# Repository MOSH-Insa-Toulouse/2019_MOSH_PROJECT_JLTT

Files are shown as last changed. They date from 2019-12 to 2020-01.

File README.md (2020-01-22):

# 2019_MOSH_PROJECT_JLTT : Kicad and Arduino LoraProject for SMART GAS sensor
> Loan Revardel / Jérémy Turi / Théo Zanchi / Thomas Lautrédou

#### <em> Key-words: </em> ```Arduino```, ```KiCad```, ```The Thing Network```, ```LoRa```, ```Node-RED```, ```IoT```, ```Gas sensor```.

This project was carried out as part of ISS (Innovative Smart Systems) 5th year at INSA Toulouse. The objective was to develop a gas sensor able to detect dangerous gases for human beings and communicating datas via Lora. Then, using the Node-RED software, we retrieved the data and displayed it on a graphical interface that the user could understand. As soon as a dangerous gas is detected, a buzzer is triggered to warn the user and avoid potential casualties. 

# Content of the Project

This repository contains : 
<ul>
<li><strong>KiCad files</strong> : We developed a shield for the gas sensor compatible with Arduino Uno (using <a href="http://kicad-pcb.org/">KiCad</a>) </li>
<li><strong>Arduino SW files</strong> : The source code we implemented on the microcontroller <a href="https://fr.rs-online.com/web/p/products/7589339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"> ATMEGA328 </a> (using <a href="https://www.arduino.cc/">Arduino IDE</a>)</li>
<li>A <strong>Node-RED dashboard</strong> to display datas retrieved from the gas sensor (using <a href="https://nodered.org/">Node-RED</a>)</li>
</ul>

# Overall components presentation
The goal of the project was to develop a prototype able to detect high dangerous gas concentration in a specific area. In this situation, a siren is triggered to alert people and avoid casualties. 

To do so, we used :
<ul>
<li>A <a href="https://store.arduino.cc/arduino-uno-rev3">Arduino Uno Board</a></li>
<li>A LoRa chip <a href="https://www.microchip.com/wwwproducts/en/RN2483">RN2483A</a></li>
<li>A <a href="http://wiki.seeedstudio.com/Grove-Gas_Sensor-MQ9/">Grove Gas Sensor (MQ9)</a></li>
<li>A potentiometer</li>
<li>A transistor <a href="http://www.vishay.com/docs/91291/91291.pdf">IRFZ44</a></li>
</ul>

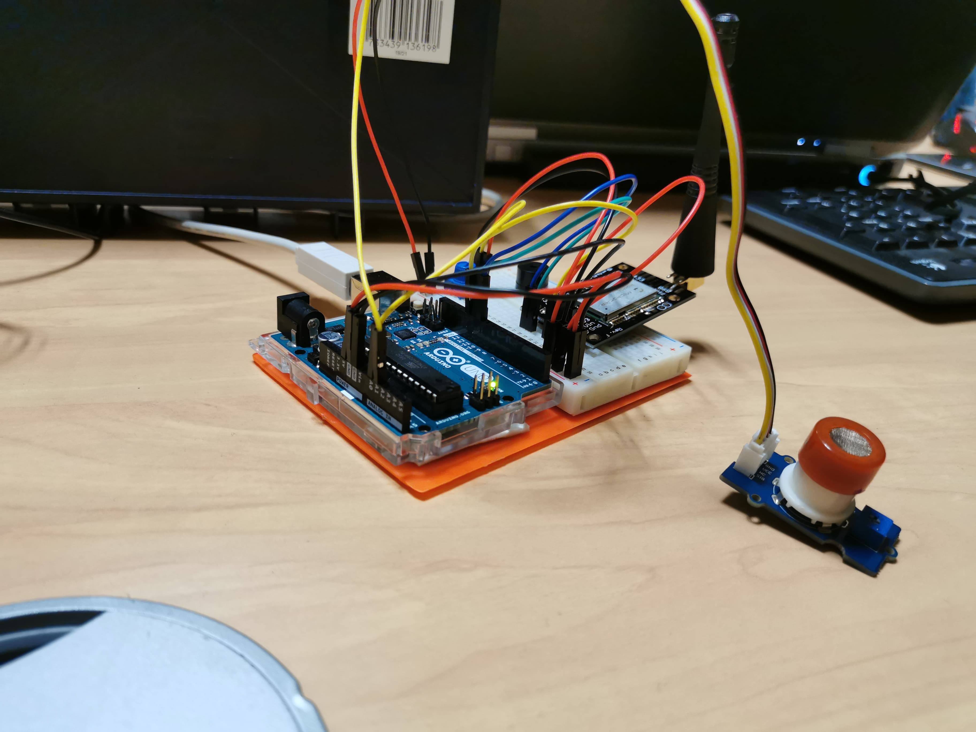
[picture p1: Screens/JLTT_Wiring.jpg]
JLTT_Wiring


### Dashboard

Then after creating a TTN application and registering our device, we used a ttn uplink node to receive the data sent to our TTN application. Finally, with some basic functions and chart blocs, we were able to display in a dashboard all the data in real time. You can find on the following figures the Node-Red flow and dashboard:

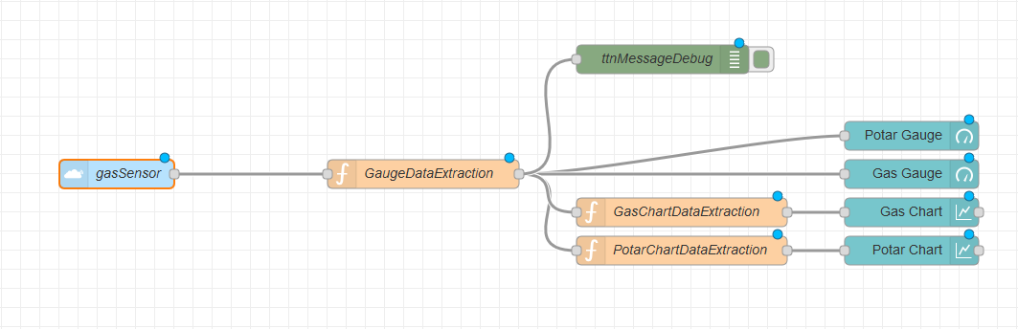
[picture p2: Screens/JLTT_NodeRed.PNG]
JLTT_NodeRed


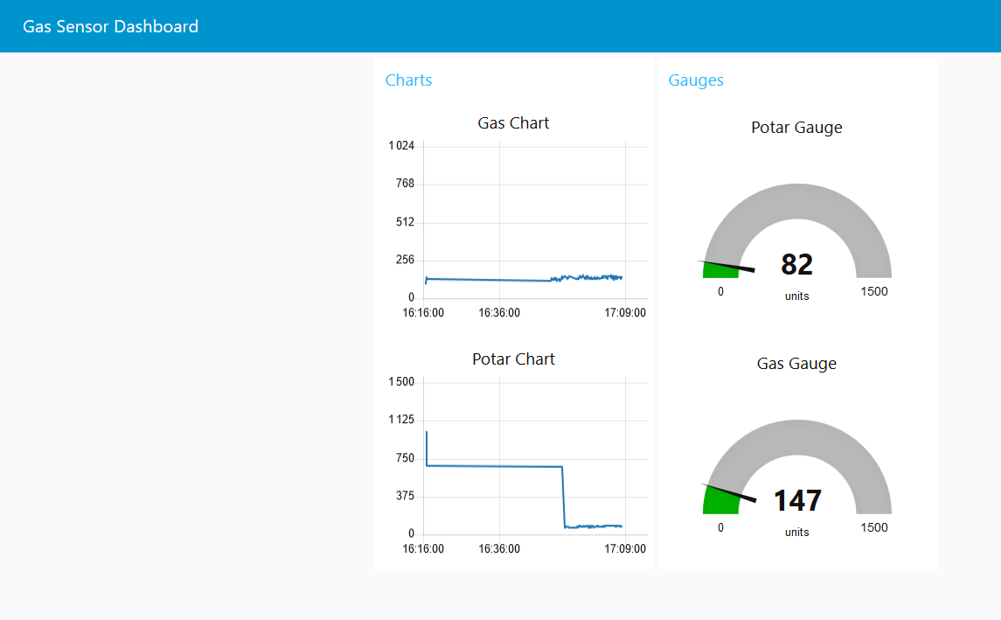
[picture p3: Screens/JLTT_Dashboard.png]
JLTT_Dashboard


### Energy consumption

During our smart device realization, we studied the energy consumption in order to optimize it. We found that we were consuming 355mA and 370mA during an emission. That is why we chose to define a sleep cycle. Indeed, every 8 seconds, our smart device wake up, read the sensor value and send it to TTN. To realize this, we used an Arduino library by convenience and lack of time:

JLTT_lowpower

This sleep cycle allows a great reduction of energy consumption and an increasing of battery lifetime.

## KiCad

In this repository, you can find KiCad files of our project. We designed an Arduino shield based on the sensor we produced at the AIME laboratory. This shield is composed of the sensor, a buzzer, a NRF2483 LoRa ship and an adapter circuit for the gas sensor. You can see on the following figure the schematics we designed with KiCad:

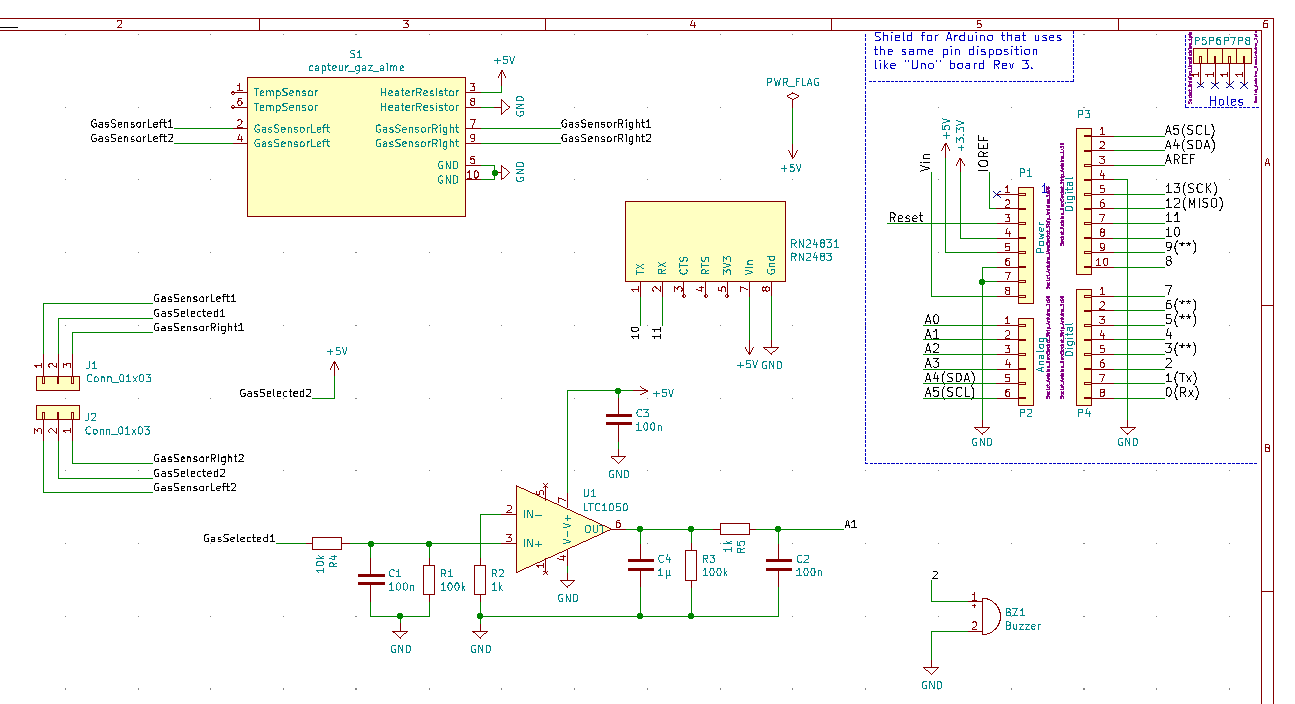
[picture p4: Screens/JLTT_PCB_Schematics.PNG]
JLTT_PCB_Schematics


After the schematics design, we exported the net file and realized the PCB routing that you can find with the following figures:

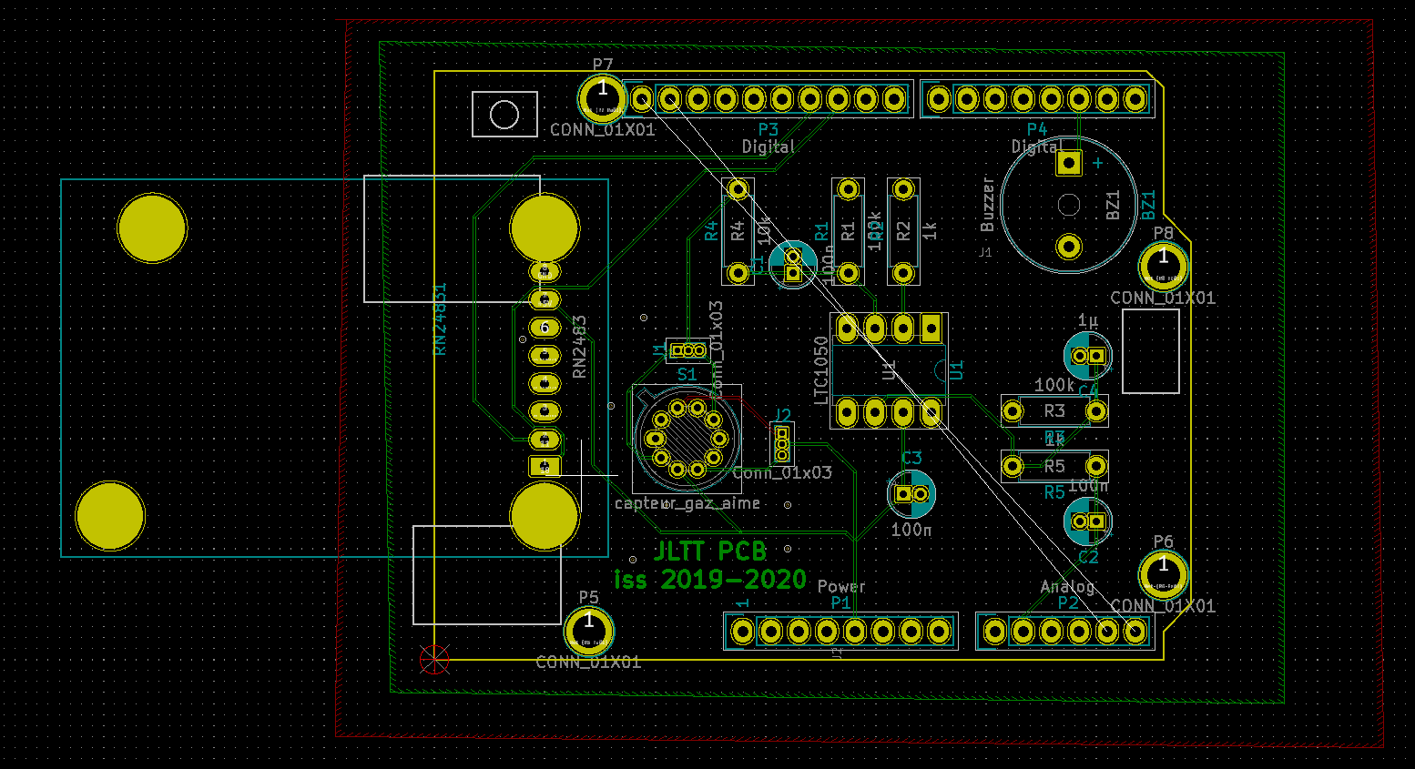
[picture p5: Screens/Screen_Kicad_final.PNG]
JLTT_PCB_Routing_1


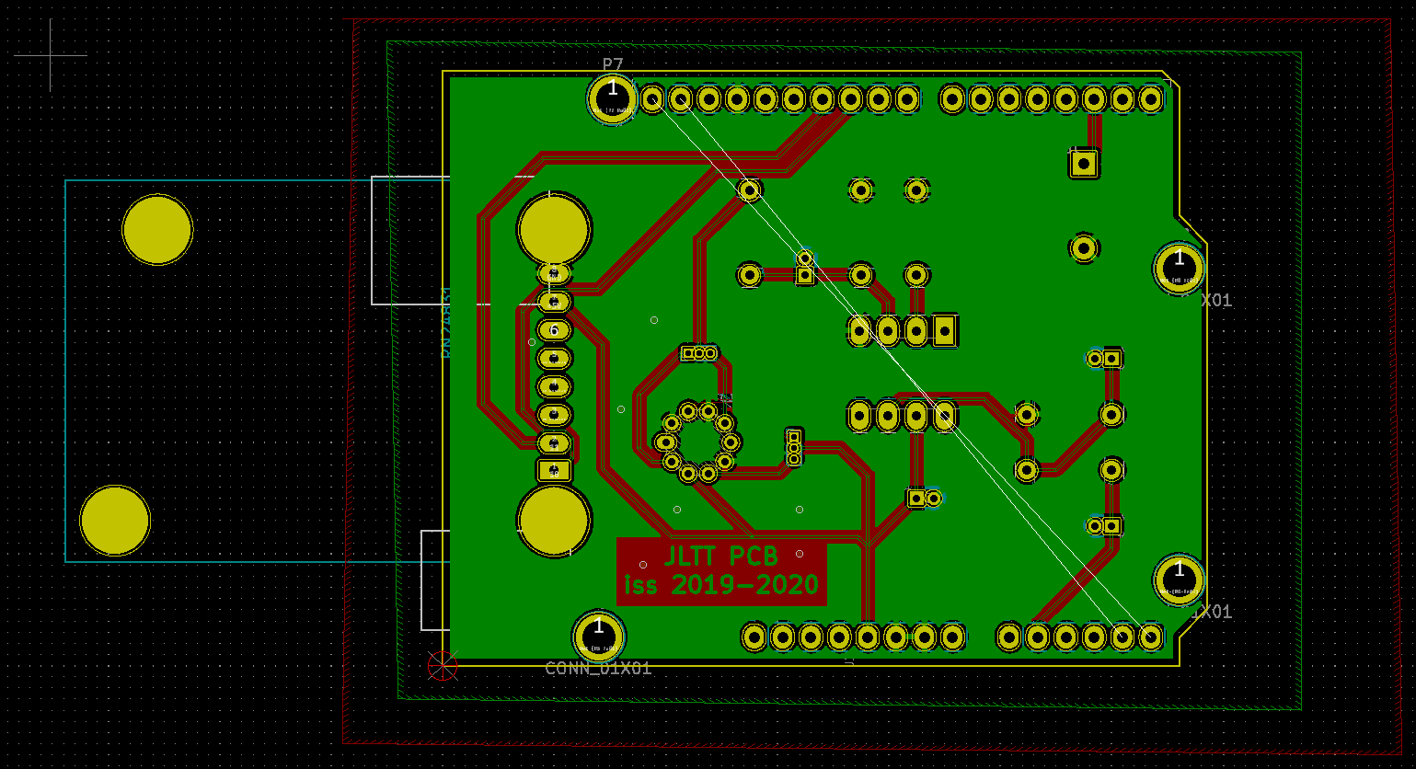
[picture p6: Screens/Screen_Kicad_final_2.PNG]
JLTT_PCB_Routing_2


Finally, we exported a 3d representation of our shield thanks to KiCad:

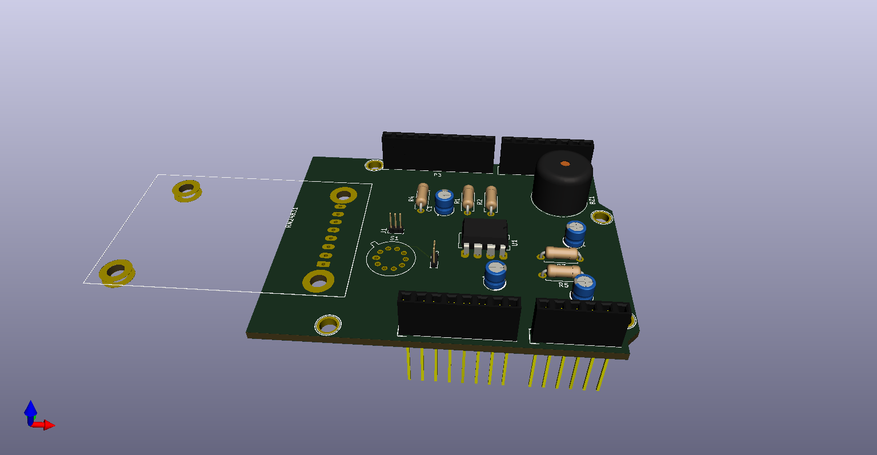
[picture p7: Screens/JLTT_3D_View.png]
JLTT_3D_View


## Conclusion

During this whole module, we were able to realize an electronic product from scratch. Indeed, from the sensor creation to the shield design and software programming, we had to mobilize several skills. Our team was composed of people with different background. That point helped us to dispatch the tasks and learn from the other experience.

To improve our project, we could for example design a PCB of a smaller size by using SMD instead of through-hole ones. Also, our PCB is only composed of the sensing and acting part of the device, a great think can be to integrate directly a micro-controller like an atmega328p in our PCB. The question of the battery and energy harvesting can be also asked and finally, we can use, to develop the dashboard, a different technology instead of Node-Red which is quite limiting.

To conclude, the whole process of sensor creation at the AIME, the PCB design with KiCad and the building of smart device during the MOSH module was a really interesting project related to IOT.

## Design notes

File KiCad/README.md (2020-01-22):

# 2019_MOSH_PROJECT_JLTT : Kicad and Arduino LoraProject for SMART GAS sensor
> Loan Revardel / Jérémy Turi / Théo Zanchi / Thomas Lautrédou

#### <em> Key-words: </em> ```Arduino```, ```KiCad```, ```The Thing Network```, ```LoRa```, ```Node-RED```, ```IoT```, ```Gas sensor```.

This project was carried out as part of ISS (Innovative Smart Systems) 5th year at INSA Toulouse. The objective was to develop a gas sensor able to detect dangerous gases for human beings and communicating datas via Lora. Then, using the Node-RED software, we retrieved the data and displayed it on a graphical interface that the user could understand. As soon as a dangerous gas is detected, a buzzer is triggered to warn the user and avoid potential casualties. 

# Content of the Project

This repository contains : 
<ul>
<li><strong>KiCad files</strong> : We developed a shield for the gas sensor compatible with Arduino Uno (using [KiCad](http://kicad-pcb.org/))</li>
<li><strong>Arduino SW files</strong></li>
<li>A <strong>Node-RED dashboard</strong> to display datas retrieved from the gas sensor</li>
</ul>

Conso : 355mA (fonctionnement normal) et 370mA (fonctionnement en émission)

Il faut mettre un Nmos en Not Gate => Quand y'a un 0 le transistor est ouvert et le gaz sensor est relié à Vdd grâce à la résistance de pull-up, et quand on met 1 le transistor est passant et donc la tension aux bornes du Gaz sensor est amenée à 0.

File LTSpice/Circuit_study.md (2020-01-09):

# Analog electronic
During two sessions we studied a transimpedance circuit to amplify the current coming from the gas sensor. The simulation is on the file Adapter_circuit.asc .

## Question 1 : check the operation in nominal conditions

In nominal conditions, the circuit amplify with a gain of approximately 100.

## Question 2 : is the impact of the LTC1050C amplifier offset acceptable ?

With a gain of 100, we have an offset of 0.5mv in output, which make a 1 digit error on the 12 bits ADC converter (the quantum is 5V/4096 = 1.2mV)

## Question 3 : is the impact of the amplifier input current acceptable ?

The impact of the input current is about 1.fA/sqrt(Hz). With a signal of 1Hz, we have an error of  <a href="https://www.codecogs.com/eqnedit.php?latex=1.8\times&space;10^-15&space;<<&space;10^-9" target="_blank">1.8\times 10^-15 << 10^-9</a>
## Question 4 : what is the cutoff frequency of each low-pass filter stage?
<ul>
<li> stage 1 : 15.9 Hz </li>
<li> stage 2 : 1.59 Hz </li>
<li> stage 1 : 1.59 kHz </li>
</ul>

## Question 5 : What is the global attenuation of a 50 Hz current noise ?

The global attenuation is 40 dB at 50Hz

## Question 6 : What is the global attenuation of a current noise occurring at the aliasing limit frequency (in the case of Arduino Uno ADC) ?

For the Arduino Uno, the sampling frequency is about <a href="https://www.codecogs.com/eqnedit.php?latex=\frac{200&space;kHz}{13}=15.4&space;kHz" target="_blank">\frac{200 kHz}{13}=15.4 kHz</a>, which makes the aliasing limit frequency at 7.7 kHz. At this frequency we have an attenuation of 108 dB.

## Question 7 : Prepare a demonstration "proof of concept" simulation with :
* a sensor, supplied with 5 volts, the conductance of which varies from 10 nS to 20 nS in 0.5 s
* a 230V RMS, 50Hz noise source, coupled with the input node through a 1pF capacitor ##

I must change in the Arbitrary current source from 50 nA to 100 nA.
We thus have I=(V(Sp,Sn)*(10n*(1+V(Gp,Gn)))).

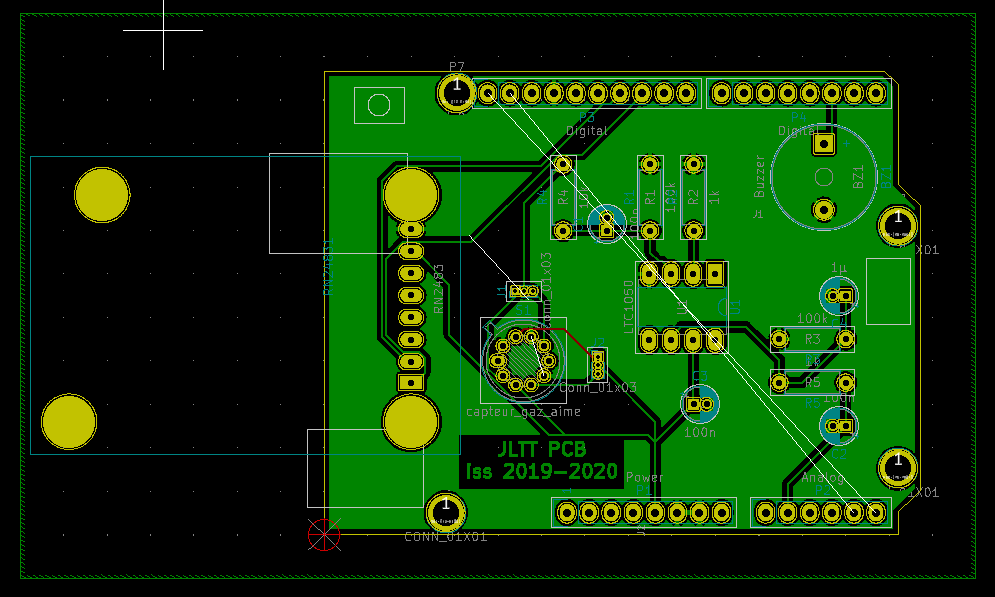
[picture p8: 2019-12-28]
Screens/JLTT_PCB_Routing_2.PNG

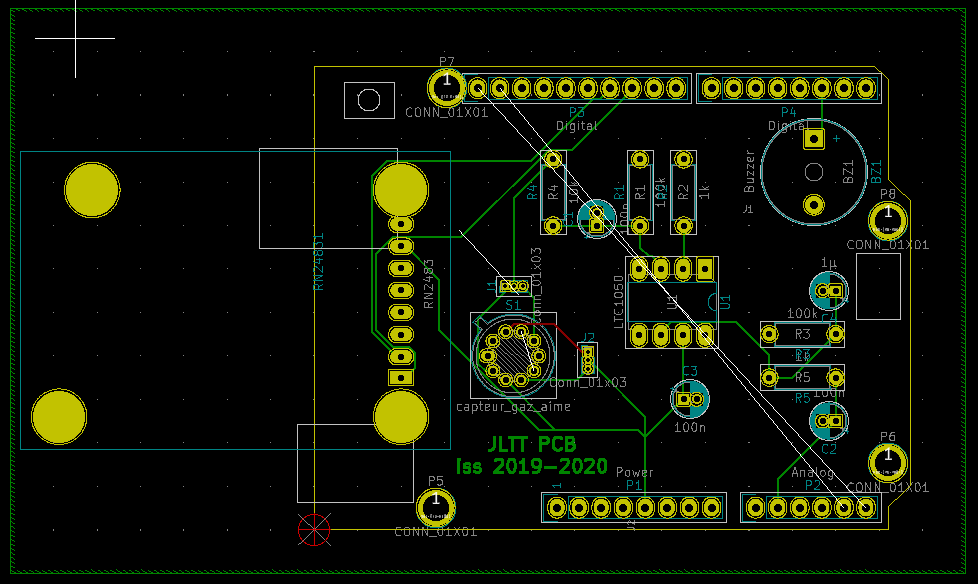
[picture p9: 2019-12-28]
Screens/JLTT_PCB_Routing_1.PNG

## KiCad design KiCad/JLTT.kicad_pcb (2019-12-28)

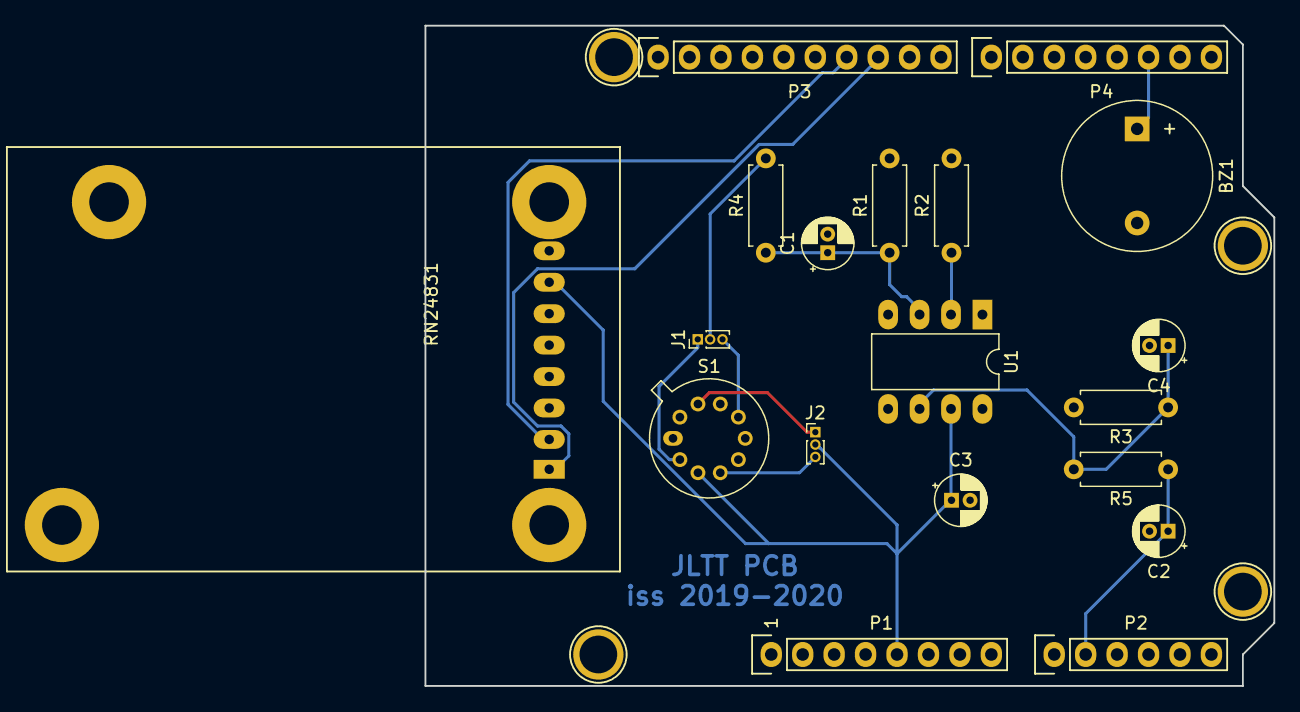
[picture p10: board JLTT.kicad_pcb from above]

Board: 2 copper layers, 68.6 x 53.3 mm, 23 parts (0 on the bottom side), 16 nets.

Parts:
BZ1: Buzzer; Buzzer_12x9.5RM7.6
C1, C2, C3: 100n; CP_Radial_D4.0mm_P1.50mm
C4: 1µ; CP_Radial_D4.0mm_P1.50mm
J1, J2: Conn_01x03; PinHeader_1x03_P1.00mm_Vertical
P1: Power; Socket_Strip_Arduino_1x08
P2: Analog; Socket_Strip_Arduino_1x06
P3: Digital; Socket_Strip_Arduino_1x10
P4: Digital; Socket_Strip_Arduino_1x08
P5, P6, P7, P8: CONN_01X01; Arduino_1pin
R1, R3: 100k; R_Axial_DIN0207_L6.3mm_D2.5mm_P7.62mm_Horizontal
R2, R5: 1k; R_Axial_DIN0207_L6.3mm_D2.5mm_P7.62mm_Horizontal
R4: 10k; R_Axial_DIN0207_L6.3mm_D2.5mm_P7.62mm_Horizontal
RN24831: RN2483; RN2483_breakout
S1: capteur_gaz_aime; TO-5-10_Window
U1: LTC1050; DIP-8_W7.62mm_LongPads

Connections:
+5V: C3.1, J2.2, P1.5, RN24831.7, S1.3, U1.7
/2: BZ1.1, P4.6
/10: P3.8, RN24831.1
/11: P3.7, RN24831.2
/A1: C2.1, P2.2, R5.1
/A4(SDA): P2.5, P3.2
/A5(SCL): P2.6, P3.1
/GasSelected1: J1.2, R4.2
/GasSensorLeft1: J1.1, S1.2
/GasSensorLeft2: J2.3, S1.4
/GasSensorRight1: J1.3, S1.7
/GasSensorRight2: J2.1, S1.9
GND: BZ1.2, C1.2, C2.2, C3.2, C4.2, P1.6, P1.7, P3.4, R1.2, R2.2, R3.2, RN24831.8, S1.5, S1.8, S1.10, U1.4
unnamed: C1.1, R1.1, R4.1, U1.3
unnamed: C4.1, R3.1, R5.2, U1.6
unnamed: R2.1, U1.2

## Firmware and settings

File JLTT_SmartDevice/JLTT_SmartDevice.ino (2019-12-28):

 /*
  * Contributors :
  * Théo Zanchi 
  * Jérémy Turi
  * Loan Revardel
  * Thomas Lautrédou
  *
  */
 
 /* Connect the RN2xx3 as follows:
 * RN2xx3 -- Arduino
 * Uart TX -- 10
 * Uart RX -- 11
 * Reset -- 12
 * Vcc -- 3.3V
 * Gnd -- Gnd
 */
 
#include <rn2xx3.h>
#include <SoftwareSerial.h>
#include <avr/sleep.h>
#include <avr/power.h>
#include <avr/wdt.h>
#include <LowPower.h>

volatile int f_wdt=1;

SoftwareSerial mySerial(10, 11); // RX, TX

// Define sensor pin
#define sensorPin A0
#define gasSensorPin A1
#define buzzerPin 2


//Threshold to trigger on the alarm buzzer or turn it off
#define THRESHOLD_HIGH 1.1
#define THRESHOLD_LOW  0.9


//create an instance of the rn2xx3 library,
//giving the software serial as port to use
rn2xx3 myLora(mySerial);

typedef enum
{
  IDLE_STATE, ALARM, MEASURE_VALUE
} T_State;

T_State myState;

// the setup routine runs once when you press reset:
void setup()
{
  //output LED pin
  pinMode(13, OUTPUT);
  led_on();

  //input sensor pin : potentiometer
  pinMode(sensorPin, INPUT);
  //input for GasSensor
  pinMode(gasSensorPin, INPUT);

  // Open serial communications and wait for port to open:
  Serial.begin(57600); //serial port to computer
  mySerial.begin(9600); //serial port to radio
  Serial.println("Startup");

  initialize_radio();

  //transmit a startup message
  myLora.tx("TTN Mapper on TTN Enschede node");

  led_off();
  delay(2000);
}

void initialize_radio()
{
  //reset rn2483
  pinMode(12, OUTPUT);
  digitalWrite(12, LOW);
  delay(500);
  digitalWrite(12, HIGH);

  delay(100); //wait for the RN2xx3's startup message
  mySerial.flush();

  //Autobaud the rn2483 module to 9600. The default would otherwise be 57600.
  myLora.autobaud();

  //check communication with radio
  String hweui = myLora.hweui();
  while(hweui.length() != 16)
  {
    Serial.println("Communication with RN2xx3 unsuccessful. Power cycle the board.");
    Serial.println(hweui);
    delay(10000);
    hweui = myLora.hweui();
  }

  //print out the HWEUI so that we can register it via ttnctl
  Serial.println("When using OTAA, register this DevEUI: ");
  Serial.println(myLora.hweui());
  Serial.println("RN2xx3 firmware version:");
  Serial.println(myLora.sysver());

  //configure your keys and join the network
  Serial.println("Trying to join TTN");
  bool join_result = false;


  /*
   * ABP: initABP(String addr, String AppSKey, String NwkSKey);
   * Paste the example code from the TTN console here:
   */
  const char *devAddr = "26011816";
  const char *nwkSKey = "47886652FC641E7AADD3DFD40041AB0E";
  const char *appSKey = "48594DB1F56E07C45049B477ECF9CFF8";

  join_result = myLora.initABP(devAddr, appSKey, nwkSKey);

  /*
   * OTAA: initOTAA(String AppEUI, String AppKey);
   * If you are using OTAA, paste the example code from the TTN console here:
   */
  //const char *devEui = "0004A30B00E94D4E";
  //const char *appEui = "70B3D57ED0025AEB";
  //const char *appKey = "0D518E5463B1F54758E6BAF2E3F51BA4";

  //join_result = myLora.initOTAA(appEui, appKey, devEui);


  while(!join_result)
  {
    Serial.println("Unable to join. Are your keys correct, and do you have TTN coverage?");
    delay(60000); //delay a minute before retry
    join_result = myLora.init();
  }
  Serial.println("Successfully joined TTN");

}

// the loop routine runs over and over again forever:
void loop()
{
  /*
   *Jérémy Turi
   *18 November 2019
   *Proposition of State Machine
   */

   /*Sleep(x:ms);
   valueGasSensor = analogRead(gasSensorPin);
   if(state == MEASURE_VALUE && valueGasSensor < threshold_Low)
   {
      buzzer_on()
      state = ALARM;
   }
   if(state == ALARM && valueGasSensor> threshold_High)
   {
      buzzer_off();
   }
   sendValue(valueGasSensor)*/

     int value = analogRead(sensorPin);
     delay(100);
     int valueGasSensor = analogRead(gasSensorPin);
     sendValueGasSensor(value, valueGasSensor);

     LowPower.idle(SLEEP_8S, ADC_OFF, TIMER2_OFF, TIMER1_OFF, TIMER0_OFF, SPI_OFF, USART0_OFF, TWI_OFF);
}

void led_on()
{
  digitalWrite(13, 1);
}

void led_off()
{
  digitalWrite(13, 0);
}

void sendValueGasSensor(int value, int v_gasSensor)
{
    led_on();
    
    char str[4];
    str[0] = (value >> 8) & 0xFF;
    str[1] = value & 0xFF;
    str[2] = (v_gasSensor >> 8) & 0xFF;
    str[3] = (v_gasSensor & 0xFF);

    Serial.print("Send sensor value : ");
    Serial.println(value);
    Serial.print("Gas Value : ");
    Serial.println(v_gasSensor);
    Serial.print("Rs/RL = ");
    Serial.println((float) (1023-v_gasSensor)/v_gasSensor);
 
    myLora.txBytes(str, sizeof(str));
    
    led_off();
    delay(200);
}

void buzzer_on()
{
  digitalWrite(buzzerPin, HIGH);
}

void buzzer_off()
{
  digitalWrite(buzzerPin, LOW);
}

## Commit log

2019-11-15 First commit arduino
2019-11-18 Rajout capteur de gaz
    Capteur de gaz input sur A1
2019-11-25 Sleep time arduino
2019-12-28 KiCad and Screens adding
2019-12-28 remove kicad
2019-12-28 Add kicad
    [JLTT.kicad_pcb, JLTT.sch]
2020-01-22 Update files for Kicad
    [JLTT.sch]
